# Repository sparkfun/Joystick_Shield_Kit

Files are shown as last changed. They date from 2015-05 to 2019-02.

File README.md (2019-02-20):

SparkFun Joystick Shield Kit
========================================

SparkFun Joystick Shield Kit

[*SparkFun Joystick Shield Kit (DEV-09760)*](https://www.sparkfun.com/products/9760)

The SparkFun Joystick Shield Kit contains all the parts you need to enable your Arduino with a joystick! 
The shield sits on top of your Arduino and turns it into a simple controller. 
Five momentary push buttons (4+ joystick select button) and a two-axis thumb joystick gives your Arduino functionality on the level of old Nintendo controllers. 

Repository Contents
-------------------

* **/Firmware** - Example code 
* **/Hardware** - Eagle design files (.brd, .sch)
* **/Production** - Production panel files (.brd)

Documentation
--------------
* **[Hookup Guide](https://www.sparkfun.com/tutorials/161)** - Basic hookup guide for the Joystick Shield.
* **[Quickstart Guide](http://www.sparkfun.com/commerce/tutorial_info.php?tutorials_id=171)** - Quickstart guide using Arduino and Processing.
* **[SparkFun Fritzing repo](https://github.com/sparkfun/Fritzing_Parts)** - Fritzing diagrams for SparkFun products.
* **[SparkFun 3D Model repo](https://github.com/sparkfun/3D_Models)** - 3D models of SparkFun products. 

License Information
-------------------
This product is _**open source**_! 

The **hardware** is released under [Creative Commons ShareAlike 4.0 International](https://creativecommons.org/licenses/by-sa/4.0/).

The **code** is beerware; if you see me (or any other SparkFun employee) at the local, and you've found our code helpful, please buy us a round!

Please use, reuse, and modify these files as you see fit. Please maintain attribution to SparkFun Electronics and release anything derivative under the same license.

Distributed as-is; no warranty is given.

- Your friends at SparkFun.

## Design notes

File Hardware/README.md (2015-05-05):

SparkFun <PRODUCT NAME> Design Files
=====================================

The .sch and .brd files hare are Eagle CAD schematic and PCB design files from SparkFun Electronics.
A freeware version of Eagle can be found [here](http://www.cadsoftusa.com/download-eagle/freeware/). 

License
---------
This product is open source! 
The hardware is released under [Creative Commons ShareAlike 4.0 International](https://creativecommons.org/licenses/by-sa/4.0/).

Please use, reuse, and modify these files as you see fit. Please maintain attribution to SparkFun Electronics and release anything derivative under the same license.

Distributed as-is; no warranty is given.

- Your friends at SparkFun.

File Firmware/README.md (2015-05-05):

SparkFun Joystick Shield Kit Firmware
===================================

* **JoystickSampleSketch** - Arduino sample sketch.

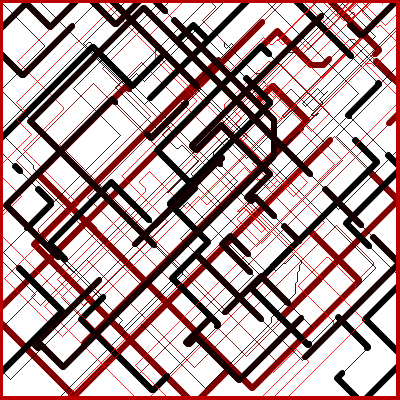
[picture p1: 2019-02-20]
Firmware/Processing/JoystickProcessingArtist/joystick-drawing-47630.png

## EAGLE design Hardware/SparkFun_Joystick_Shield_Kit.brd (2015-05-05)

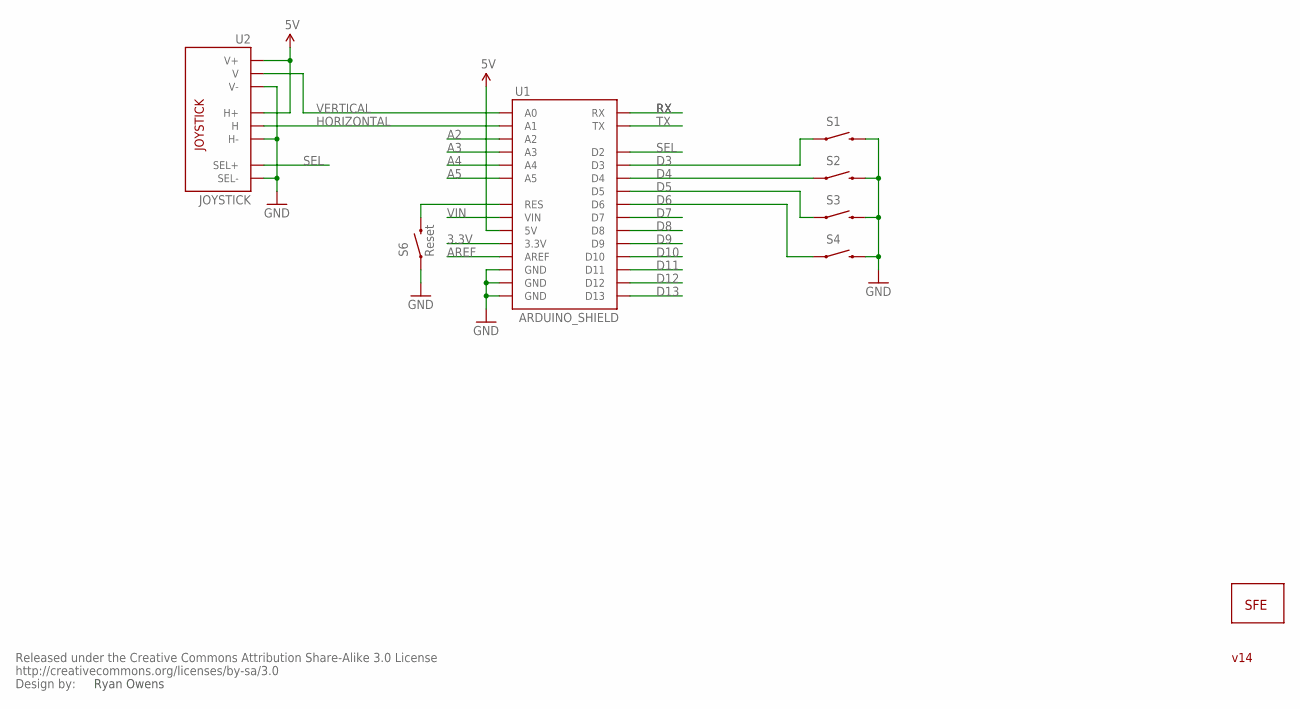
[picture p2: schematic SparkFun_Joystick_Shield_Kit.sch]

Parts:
JP1: LOGO-SFENEW; SFE-NEW-WEBLOGO
S1, S2, S3, S4: SWITCH-MOMENTARY-212MM; TACTILE-PTH-12MM
S6: Reset; TACTILE-PTH
U1: ARDUINO_SHIELD; DUEMILANOVE_SHIELD
U2: JOYSTICK
U$3: CREATIVE_COMMONS

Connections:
3.3V: U1.3.3V
5V: U1.5V, U2.H1 (H+), U2.V1 (V+)
A2: U1.A2
A3: U1.A3
A4: U1.A4
A5: U1.A5
AREF: U1.AREF
D3: S1.1, U1.D3
D4: S2.1, U1.D4
D5: S3.1, U1.D5
D6: S4.1, U1.D6
D7: U1.D7
D8: U1.D8
D9: U1.D9
D10: U1.D10
D11: U1.D11
D12: U1.D12
D13: U1.D13
GND: S1.3 (2), S2.3 (2), S3.3 (2), S4.3 (2), S6.1, U1.GND@0 (GND), U1.GND@1 (GND), U1.GND@2 (GND), U2.B2A (SEL-), U2.H3 (H-), U2.V3 (V-)
HORIZONTAL: U1.A1, U2.H2 (H)
unnamed: S6.3 (2), U1.RES
RX: U1.RX
SEL: U1.D2, U2.B1A (SEL+)
TX: U1.TX
VERTICAL: U1.A0, U2.V2 (V)
VIN: U1.VIN

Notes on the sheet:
Ryan Owens
v14

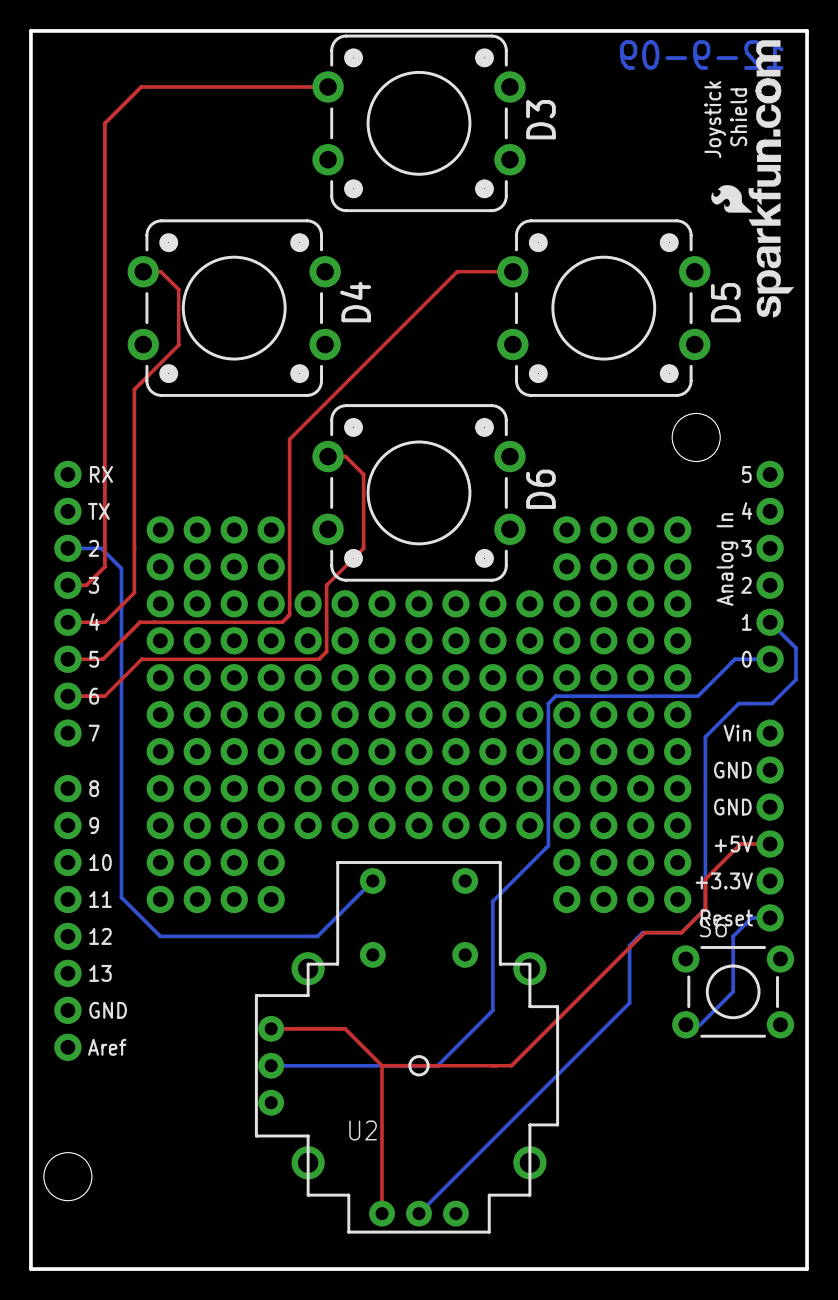
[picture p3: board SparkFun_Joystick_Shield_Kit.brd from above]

Board: 2 copper layers, 53.3 x 85.1 mm, 9 parts (0 on the bottom side), 10 nets.

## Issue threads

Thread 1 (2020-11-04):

Documetation link are not working

MrMorrisonsLab, 2020-11-04:
I am tiring to assemble and use this product and the documentation links are not working. Can you Update the links please?

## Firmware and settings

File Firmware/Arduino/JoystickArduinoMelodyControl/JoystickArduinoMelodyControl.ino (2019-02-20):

/*JoystickArduinoMelodyControl.ino

  Description:
    A sketch to demonstrate using a joystick to control the
  tempo and pitch of a "melody".

  (And you thought the standard Melody sketch was annoying!)

  How to use:

    - Connect joystick shield to your Arduino
    - Connect piezo buzzer to your Arduino using breadboard and jumper wire
       - Positive pin of buzzer to Arduino pin 9
       - Other pin of buzzer to Arduino ground (GND)
    - Upload this sketch to your Arduino
    - Move joystick
       - Moving left and right controls the tempo
       - Moving up and down controls the pitch

  Requires:

    - Arduino
    - SparkFun Joystick Shield

  This sketch is a lightly modified version of<http://www.arduino.cc/en/Tutorial/Melody>
  for SparkFun Arduino Inventor's Kit CIRC-JOY

*/

// Store the Arduino pin associated with each axis of the joystick input
const int PIN_ANALOG_X = 0;
const int PIN_ANALOG_Y = 1;


const int speakerPin = 9;

int length = 15; // the number of notes
char notes[] = "ccggaagffeeddc "; // a space represents a rest
int beats[] = { 1, 1, 1, 1, 1, 1, 2, 1, 1, 1, 1, 1, 1, 2, 4 };
int tempo = 300;

void playTone(int tone, int duration) {
  for (long i = 0; i < duration * 1000L; i += tone * 2) {
    digitalWrite(speakerPin, HIGH);
    delayMicroseconds(tone);
    digitalWrite(speakerPin, LOW);
    delayMicroseconds(tone);
  }
}

void playNote(char note, int duration) {
  char names[] = { 'c', 'd', 'e', 'f', 'g', 'a', 'b', 'C' };
  int tones[] = { 1915, 1700, 1519, 1432, 1275, 1136, 1014, 956 };

  // play the tone corresponding to the note name
  for (int i = 0; i < 8; i++) {
    if (names[i] == note) {
      // We modify the pitch of the note to be played based on the vertical position
      // of the joystick:
      playTone(tones[i] + map(analogRead(PIN_ANALOG_Y), 0, 1023, 959, -959), duration);
    }
  }
}

void setup() {
  pinMode(speakerPin, OUTPUT);
}

void loop() {
  for (int i = 0; i < length; i++) {
    // We set the tempo based on the horizontal position of the joystick:
    tempo = map(analogRead(PIN_ANALOG_X), 0, 1023, 500, 100);
    if (notes[i] == ' ') {
      delay(beats[i] * tempo); // rest
    } else {
      playNote(notes[i], beats[i] * tempo);
    }

    // pause between notes
    delay(tempo / 2);
  }
}

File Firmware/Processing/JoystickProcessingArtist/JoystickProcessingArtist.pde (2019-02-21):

/*JoystickProcessingArtist.pde
  
  A simple drawing program to demonstrate joystick control


  NOTE: This is a sketch for the Processing language and won't
        compile in the Arduino IDE.

  
  How to use:
  
    * Use the joystick to control on-screen "pen"
    * Left/Right buttons decrease/increase line color brightness
    * Up/Down buttons change line color hue
    * Select (pressing on the joystick) makes the line thicker
    * Pressing Left & Right buttons together saves a snapshot of the drawing
      in the sketch folder
  
  Requires:
  
    * 'StandardFirmata' sketch needs to be uploaded to the Arduino
      (Found in File > Examples > Firmata > StandardFirmata in the Arduino IDE)

    * The Arduino library needs to be installed for Processing from:

         <http://www.arduino.cc/playground/Interfacing/Processing>
         
    * Written for Processing IDE v2.2.1 and below. May not run for Processing 3
    
         <https://processing.org/download/>

  Written for SparkFun Arduino Inventor's Kit CIRC-JOY

 */

// There are a number of methods you can choose to use to determine the relationship
// between the position of the joystick and the position of the drawing point on
// the screen. Change POSITION_METHOD to be equal to 0, 1, 2 or 3 to try out the
// different variations.
// See the comments in the code below to find out how each method works.
final int POSITION_METHOD = 0;

// Import classes required to communicate with the Arduino
import processing.serial.*;
import cc.arduino.*;

Arduino arduino;


// Store the Arduino pin associated with each input
final int PIN_BUTTON_SELECT = 2; // Select button is triggered when joystick is pressed
final int PIN_BUTTON_RIGHT = 3;
final int PIN_BUTTON_UP = 4;
final int PIN_BUTTON_DOWN = 5;
final int PIN_BUTTON_LEFT = 6;

final int PIN_ANALOG_X = 0;
final int PIN_ANALOG_Y = 1;

// Store list of button pins which need pull-up resistors activated
int[] BUTTON_PINS = {PIN_BUTTON_SELECT,
                     PIN_BUTTON_LEFT, PIN_BUTTON_RIGHT,
                     PIN_BUTTON_UP, PIN_BUTTON_DOWN};


// Dimensions in pixels of drawing area
final int WINDOW_WIDTH = 400;
final int WINDOW_HEIGHT = 400;

// Store the maximum possible values of the X & Y co-ordinates.
// Because the first pixel in each dimension is 0 the maximum value is one
// less than the actual width or height.
final int MAX_X = WINDOW_WIDTH - 1;
final int MAX_Y = WINDOW_HEIGHT - 1;


// Set initial "pen" colour hue and brightness
int current_hue = 30;
int current_bright = 50;

// Set the initial pen location to the centre of the window.
int draw_x = WINDOW_WIDTH/2;
int draw_y = WINDOW_HEIGHT/2;


// It takes several seconds before the input readings are valid
// because of the time it takes for Processing to establish
// the connection with the Arduino. We don't want to draw anything
// until we know the input readings are valid so we use this variable
// to track if the connection to the Arduino is ready and providing valid
// readings.
boolean arduinoIsReady = false;


void setup() {
  // Set the drawing window size
  size(WINDOW_WIDTH, WINDOW_HEIGHT);

  // We will specify colors as Hue, Saturation and Brightness (HSB) values.
  // The maximum value will be 100%.
  colorMode(HSB, 100);
  
  // Set the background color as white
  background(color(0, 0, 100));
  

  // Prints a list to the console of all the serial devices 
  // connected to the computer
  println(Arduino.list());
  
  // We assume that the Arduino is the first device in the list,
  // if it's not the first device you need to change the '0'.  
  arduino = new Arduino(this, Arduino.list()[0], 57600);


  // Loop over the array of pushbutton pins and specify each as an input
  // and enable the pin's "pull-up" resistor--this means the shield
  // doesn't need to have resistors on it.
  // We use a loop to avoid repeating the pinMode/digitalWrite code.
  // Note that when a pull-up resistor is used on a pin the
  // meaning of the values read are reversed compared to their
  // usual meanings:
  //    * HIGH = the button is not pressed
  //    * LOW = the button is pressed    
  for (int index = 0 ; index < BUTTON_PINS.length; index++) {
    arduino.pinMode(BUTTON_PINS[index], Arduino.INPUT);  
    arduino.digitalWrite(BUTTON_PINS[index], Arduino.HIGH);
  }

}


void draw() {
  // Note: It seems to take a few seconds before the joystick reading is accurate.
  //       I think this is due to the bootloader and other delays in receiving
  //       a response from Firmata. 
  //       A semi-reliable method for determining if we've got a real response
  //       from Firmata is to check the joystick returns a non-zero position in
  //       each axis. Obviously this fails if the joystick is positioned fully down
  //       and left when we start--so don't do that. :)
  //       We don't draw anything until we determine that we've got a real response.
  //       If we calibrated the centre point first we might increase reliability.
  if (!arduinoIsReady) {
    if (!((arduino.analogRead(PIN_ANALOG_X) == 0) && (arduino.analogRead(PIN_ANALOG_Y) == 0))) {
      arduinoIsReady = true;
    } else {
      return;
    }
  }


  // Change the current hue based on the state of the up and down buttons.
  if (arduino.digitalRead(PIN_BUTTON_UP) == arduino.LOW) {
    current_hue++;
  }
 
  if (arduino.digitalRead(PIN_BUTTON_DOWN) == arduino.LOW) {
    current_hue--;      
  }
  
  current_hue = constrain(current_hue, 0, 100);


  // We take a screenshot when both the left and right buttons are pressed. 
  if ((arduino.digitalRead(PIN_BUTTON_RIGHT) == arduino.LOW) &&
      (arduino.digitalRead(PIN_BUTTON_LEFT) == arduino.LOW)) {
        // Note there is little delay between screenshots.
        saveFrame("joystick-drawing-####.png");
  }
  

  // Change the current brightness based on the state of the left and right buttons
  if (arduino.digitalRead(PIN_BUTTON_RIGHT) == arduino.LOW) {
    current_bright++;
  }
 
  if (arduino.digitalRead(PIN_BUTTON_LEFT) == arduino.LOW) {
    current_bright--;      
  }
  
  current_bright = constrain(current_bright, 0, 100);

  fill(color(current_hue, 100, current_bright));
  stroke(color(current_hue, 100, current_bright));


  // Use one of four methods of mapping the current joystick position to 
  // a location on screen.
  if (POSITION_METHOD == 0) {
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

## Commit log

2015-05-05 Adding hardware, updating READMEs, adding example sketch
    [SparkFun_Joystick_Shield_Kit.brd, SparkFun_Joystick_Shield_Kit.sch]
2019-02-20 Arduino and Processing Examples
    Include Joystick Arduino and Processing Examples

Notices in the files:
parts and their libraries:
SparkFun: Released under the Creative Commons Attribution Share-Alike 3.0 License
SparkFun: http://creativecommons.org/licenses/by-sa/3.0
